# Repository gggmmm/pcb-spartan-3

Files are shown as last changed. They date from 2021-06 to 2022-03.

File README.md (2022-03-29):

# pcb-spartan-3

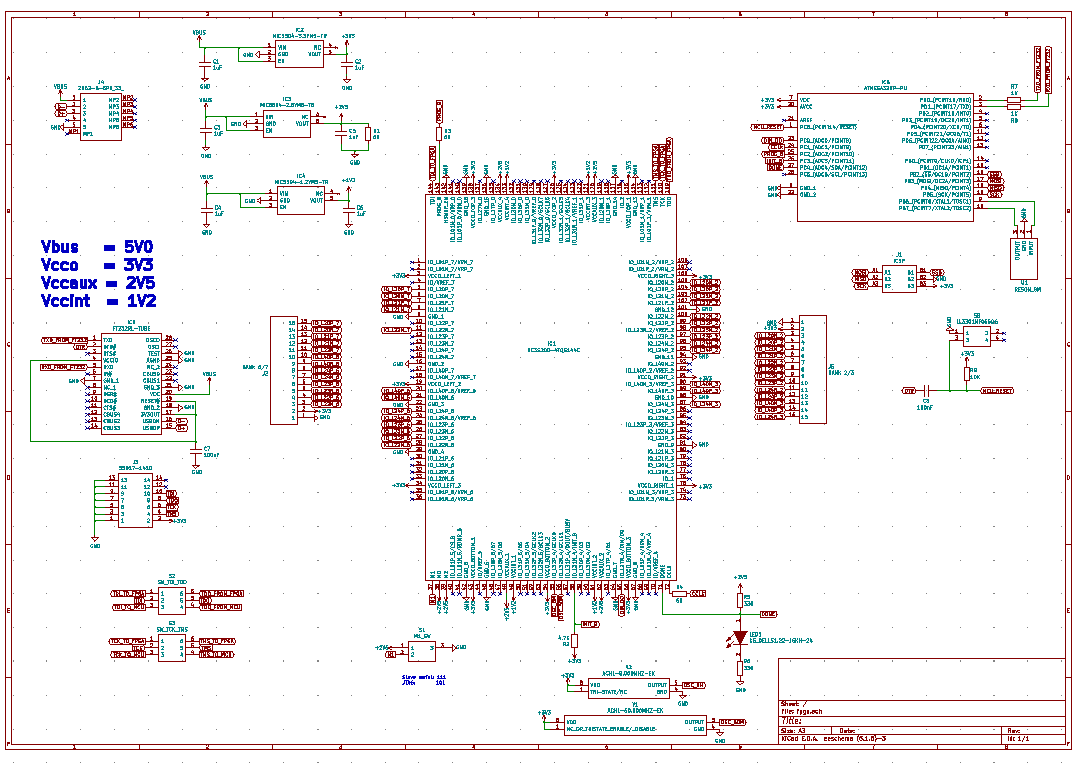
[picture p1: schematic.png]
PCB schematic


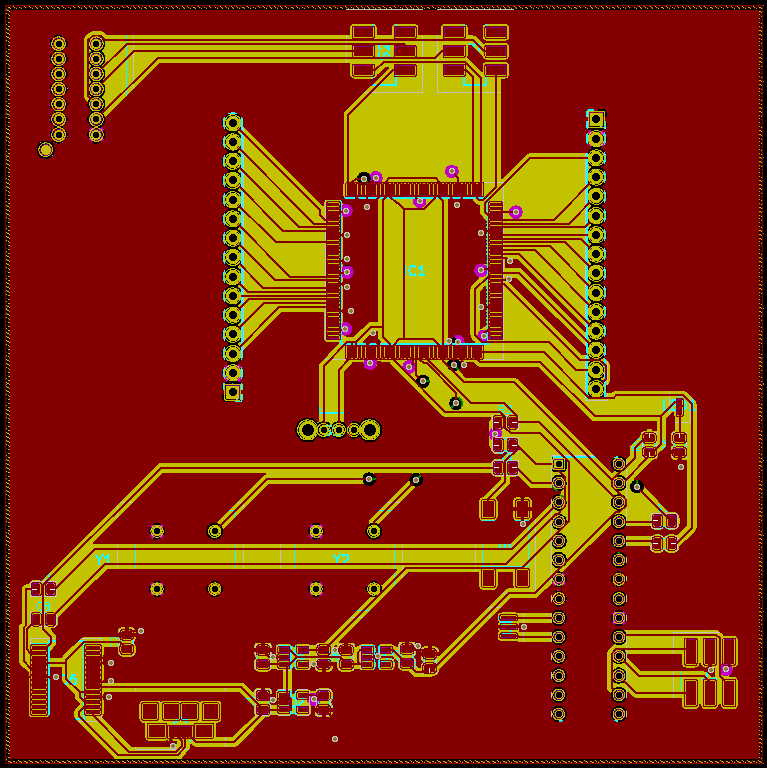
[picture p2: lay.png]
PCB layout


First attempt at PCB design using KiCad 5.1. This design contains Xilinx Spartan-3 programmable either through JTAG or Atmega328p.

Eeschema produces some warnings, due to the fact I have used different grids, which I learned later to be discouraged.

In the library, there are more footprints/models than actually used. I did not remove the unused ones.

Tested only on Windows 10.

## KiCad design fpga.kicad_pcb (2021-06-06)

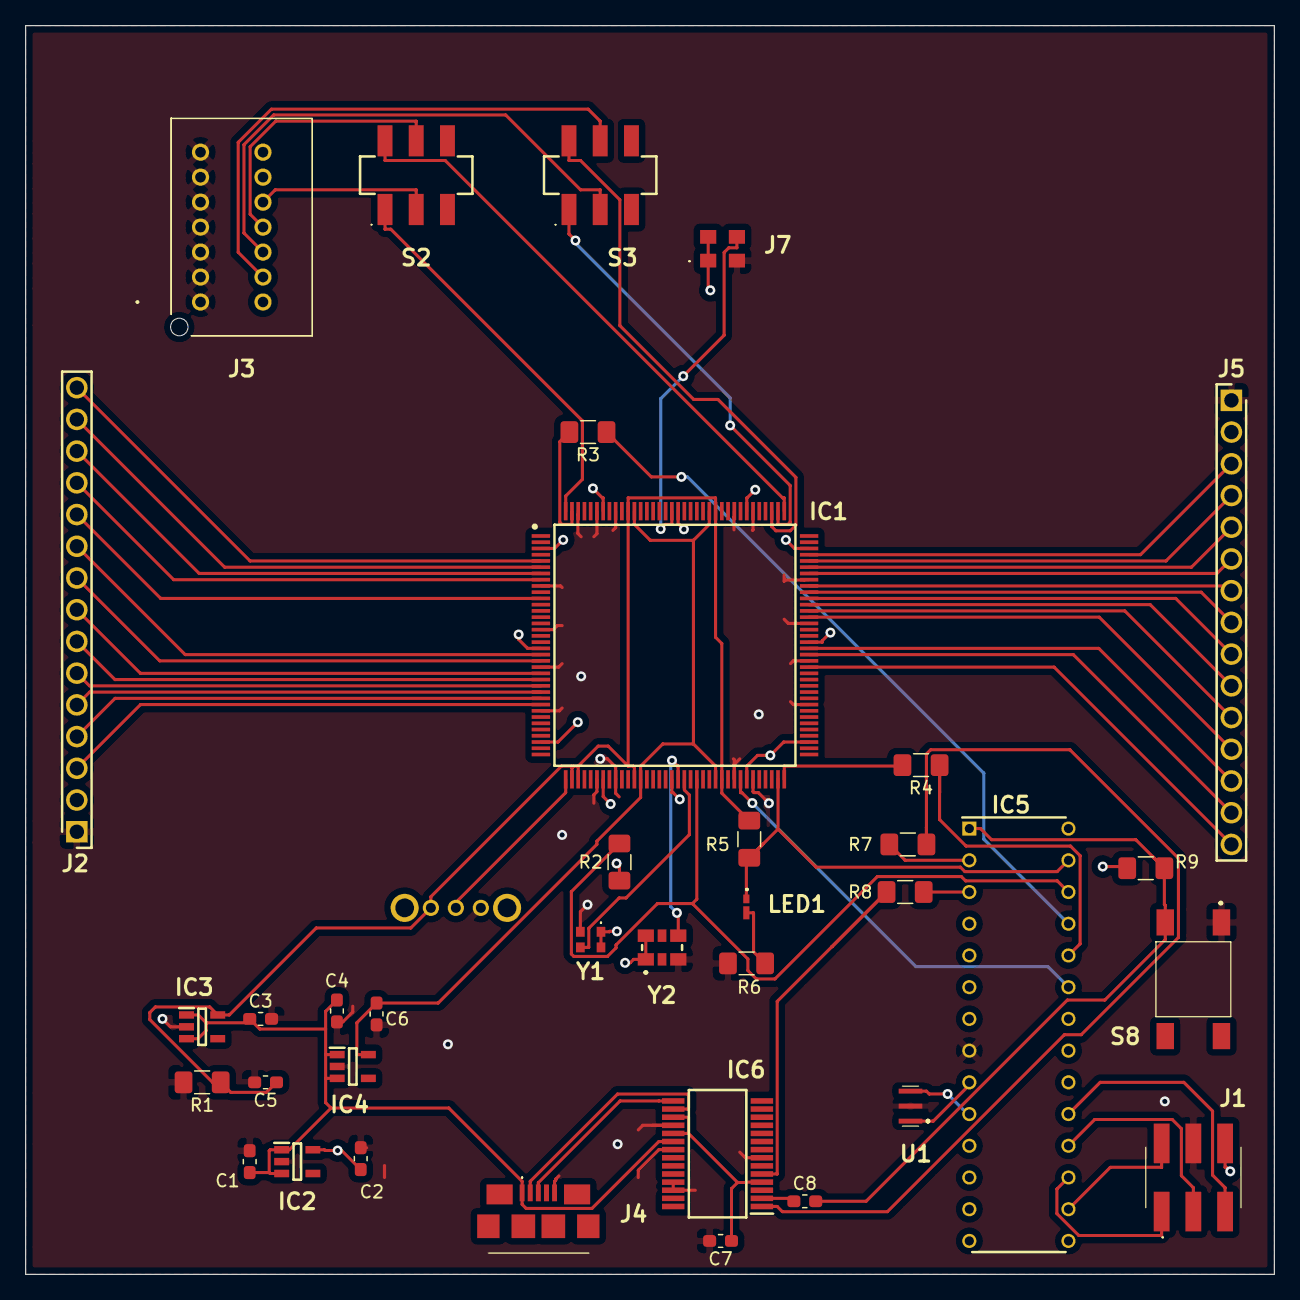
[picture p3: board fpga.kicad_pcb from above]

Board: 4 copper layers, 100.0 x 100.0 mm, 37 parts (1 on the bottom side), 66 nets.

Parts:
C1, C2, C3, C4, C5, C6: 1uF; C_0603_1608Metric_Pad1.05x0.95mm_HandSolder
C7, C8: 100nF; C_0603_1608Metric_Pad1.05x0.95mm_HandSolder
IC1: XC3S200-4TQG144C; QFP50P2200X2200X160-144N
IC2: MIC5504-3.3YM5-TR; SOT95P280X145-5N
IC3: MIC5504-2.5YM5-T5; SOT95P280X145-5N
IC4: MIC5504-1.2YM5-TR; SOT95P280X130-5N
IC5: ATMEGA328P-PU; DIP794W53P254L3467H457Q28N
IC6: FT232RL-TUBE; SOP65P780X200-28N
J1: ICSP; 10129383906002ALF
J2: BANK 6/7; HDRV15W67P0X254_1X15_3785X236X1117P
J3: 55917-1410; 559171410
J4: ZX62-B-5PA_33_; ZX62B5PA33
J5: BANK 2/3; HDRV15W67P0X254_1X15_3785X236X1117P
J7: OSC 32.768 kHz; ECS327MVATX3CNTR
LED1: KG_DELLS1.22-JGKH-24; KGDELLS122JGKH24
R1, R3, R4: 68; R_1206_3216Metric_Pad1.42x1.75mm_HandSolder
R2: 4.7K; R_1206_3216Metric_Pad1.42x1.75mm_HandSolder
R5, R6: 330; R_1206_3216Metric_Pad1.42x1.75mm_HandSolder
R7, R8: 1K; R_1206_3216Metric_Pad1.42x1.75mm_HandSolder
R9: 10K; R_1206_3216Metric_Pad1.42x1.75mm_HandSolder
S1: M1_SW; OS102011MA1QN1
S2: SW_TDI_TDO; JS202011SCQN
S3: SW_TCK_TMS; JS202011SCQN
S8: LL3301NF065QG
U1: RESON_8M; CSTNE16M0V530000R0
Y1: OSC 50 MHz; DSC6101JL3B0500000
Y2: OSC 200 MHz; XLH335200000000X

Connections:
+1V2: C6.1, IC1.49, IC1.61, IC1.121, IC1.133, IC4.5
+2V5: C5.1, IC1.38, IC1.39, IC1.48, IC1.62, IC1.120, IC1.134, IC3.5, R1.1, R5.2, S1.1
+3V3: C2.1, IC1.3, IC1.19, IC1.34, IC1.43, IC1.54, IC1.66, IC1.75, IC1.91, IC1.106, IC1.115, IC1.126, IC1.138, IC2.5, IC5.7, IC5.20, J1.B3, J2.2, J3.2, J5.2, J7.1, J7.4, R2.1, R9.2, Y1.1, Y1.4, Y2.1, Y2.6
CCLK: IC5.24, R4.1
D+: IC6.15, J4.3
D-: IC6.16, J4.2
DIN_DO: IC1.65, IC5.23
DONE: IC1.71, IC5.27, LED1.1, R5.1
DTR: C8.1, IC6.2
GND: C1.2, C2.2, C3.2, C4.2, C5.2, C6.2, C7.2, IC1.9, IC1.16, IC1.22, IC1.29, IC1.42, IC1.45, IC1.64, IC1.67, IC1.81, IC1.88, IC1.94, IC1.101, IC1.114, IC1.117, IC1.136, IC1.139, IC1.142, IC2.2, IC3.2, IC4.2, IC5.8, IC5.22, IC6.7, IC6.18, IC6.21, IC6.25, IC6.26, J1.B2, J2.1, J3.1, J3.3, J3.5, J3.7, J3.9, J3.11, J3.13, J4.5, J5.1, J7.2, R1.2, R6.1, S1.3, S8.1, U1.2, Y1.2, Y2.3
INIT_B: IC1.58, IC5.26, R2.2
IO_L20N_2: IC1.105, J5.3
IO_L20N_7: IC1.6, J2.14
IO_L20P_2: IC1.104, J5.4
IO_L20P_7: IC1.5, J2.15
IO_L21N_2: IC1.103, J5.5
IO_L21N_7: IC1.8, J2.12
IO_L21P_2: IC1.102, J5.6
IO_L21P_7: IC1.7, J2.13
IO_L22N_2: IC1.100, J5.7
IO_L22N_6: IC1.28, J2.3
IO_L22N_7: IC1.11, J2.11
IO_L22P_2: IC1.99, J5.8
IO_L22P_6: IC1.27, J2.4
IO_L23N_2: IC1.98, J5.9
IO_L23N_6: IC1.26, J2.5
IO_L23P_2: IC1.97, J5.10
IO_L23P_6: IC1.25, J2.6
IO_L24N_2: IC1.96, J5.11
IO_L24N_3: IC1.87, J5.15
IO_L24N_6: IC1.24, J2.7
IO_L24P_2: IC1.95, J5.12
IO_L24P_6: IC1.23, J2.8
IO_L40N_3: IC1.90, J5.13
IO_L40N_6: IC1.21, J2.9
IO_L40P_3: IC1.89, J5.14
IO_L40P_6: IC1.20, J2.10
M1: IC1.37, S1.2
MCU_RESET: C8.2, IC5.1, R9.1, S8.3
MISO: IC5.18, J1.A2
MOSI: IC5.17, J1.A1
unnamed: C7.1, IC6.4, IC6.17, IC6.19
unnamed: IC1.72, R4.2
unnamed: IC1.143, R3.2
unnamed: IC5.2, R7.2
unnamed: IC5.3, R8.2
unnamed: IC5.9, U1.1
unnamed: IC5.10, U1.3
unnamed: LED1.2, R6.2
OSC_32K768: IC1.127, J7.3
OSC_50M: IC1.55, Y2.4
OSC_200M: IC1.56, Y1.3
PROG_B: IC5.25, R3.1
RXD_FROM_FT232: IC6.5, R8.1
SCK: IC5.19, J1.A3
SSB: IC5.16, J1.B1
TCK: J3.6, S3.2
TCK_TO_FPGA: IC1.110, S3.1
TDI: J3.10, S2.2
TDI_TO_FPGA: IC1.144, S2.1
TDO: J3.8, S2.5
TDO_FROM_FPGA: IC1.109, S2.6
TMS: J3.4, S3.5
TMS_TO_FPGA: IC1.111, S3.6
TXD_FROM_FT232: IC6.1, R7.1
VBUS: C1.1, C3.1, C4.1, IC2.1, IC2.3, IC3.1, IC3.3, IC4.1, IC4.3, IC6.20, J4.1

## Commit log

2021-06-06 Initial commit: schematic and layout done
    [fpga.kicad_pcb, fpga.sch]
2021-06-06 rotated USB connector
    [fpga.kicad_pcb]
